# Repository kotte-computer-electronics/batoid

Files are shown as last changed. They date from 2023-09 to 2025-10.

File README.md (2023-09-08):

# batoid

_A 3D-printable, handwired, ergonomic keyboard_

Hero image

## Small footprint, big personality

Kotte Computer Electronics is proud to present the latest revolution in ergonomic personal computing peripherals - the Batoid Erlanomic keyboard.

The tilted, split layout of 43 staggered keys with an incline of 8 degrees is designed with your optimal performance in mind.

The two built in LED indicators conveniently show what side of the keyboard you are typing on, and blinks in a forwards-and-back manner during high typing speeds.

The bottom row features one extra key, this gives you the opportunity to add an easily accessible extra modifier.

The case is held together with M3 nuts and bolts, and the 3D-printed plate is mounted with a 3-5mm sealing strip, giving you a comfortable, soft typing experience with materials found at your local hardware store.

The Kotte Computer Electronics Batoid allows you to maximize your productivity and enjoyment, at work and home.

## Inspiration

I've wanted an Alice-like 40's board for quite a while, so when @theerland on the Swedish MK-Discord server said he wanted one too, inspiration struck.

The name Batoid comes from the fact that it looks a bit like a member of the batoidea ~family~ superorder of fish (thanks to [KBD news](https://kbd.news/Batoid-2112.html) for the correction). [Here's one I met a couple of years ago](./kotte-with-batoid.png). 

The keyboard looks pretty happy, and blinks it's eyes when you type - a feature that is completely useless, but cute as shit.

## Sound test

Don't believe in the quality of the mounting? [Here's a sound test](https://www.youtube.com/watch?v=9PGgU88DhRI).

## Some more glam shots, by Erland

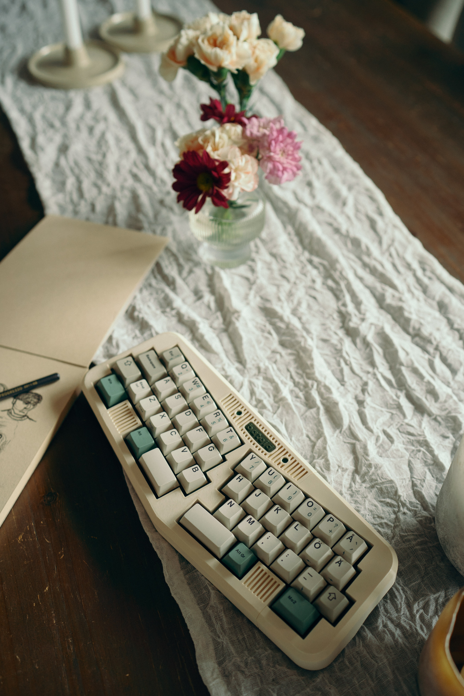
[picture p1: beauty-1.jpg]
Beauty Shot 1

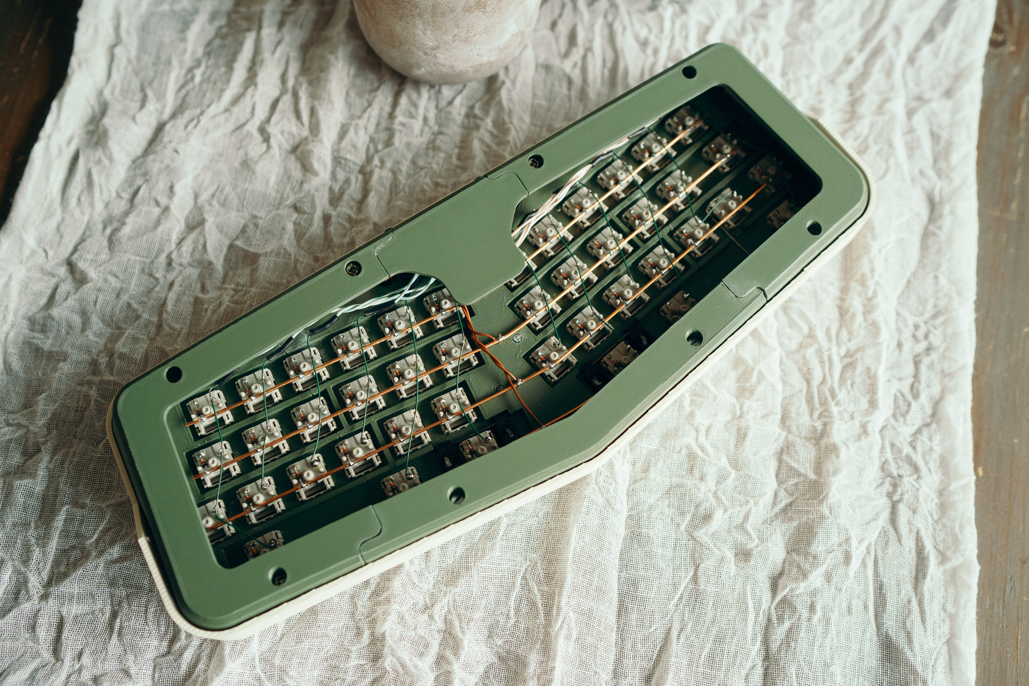
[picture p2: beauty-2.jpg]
Beauty Shot 2


## Some not as beautiful (but informative) CAD shots

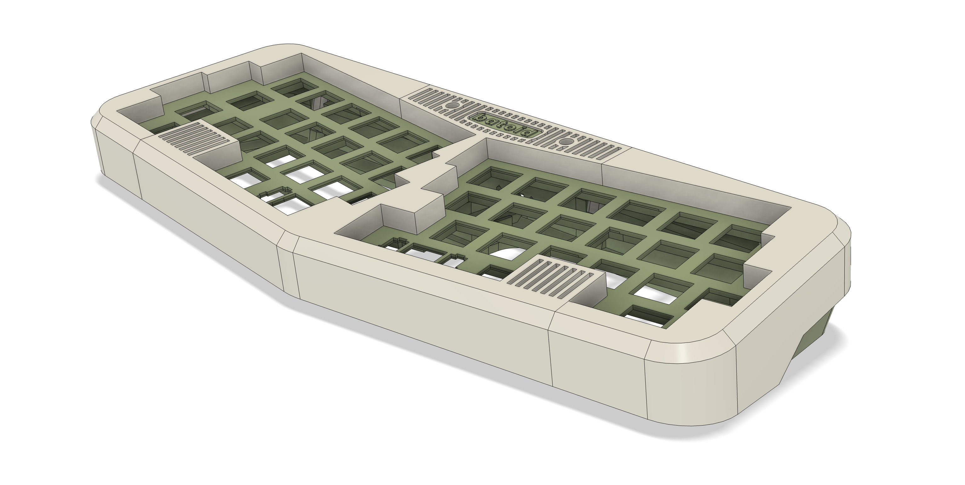
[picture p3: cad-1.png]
CAD 1

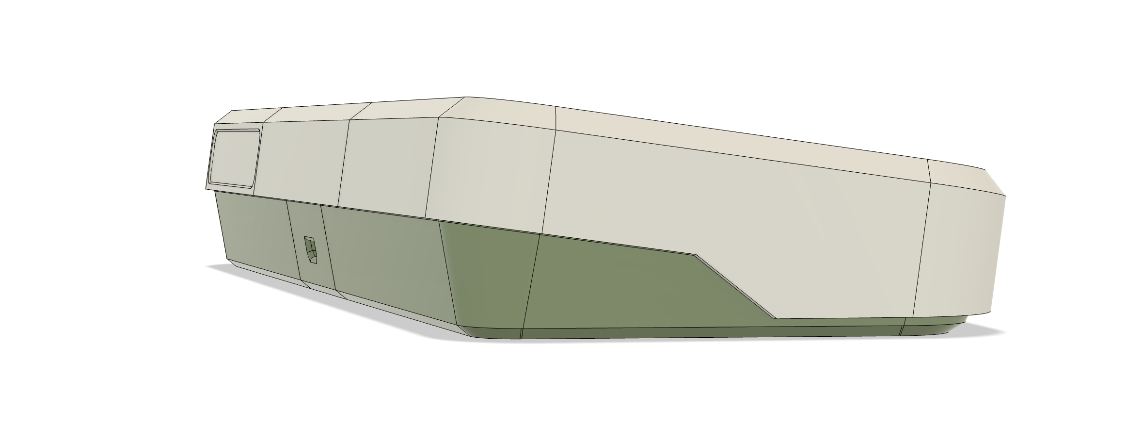
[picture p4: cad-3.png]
CAD 3

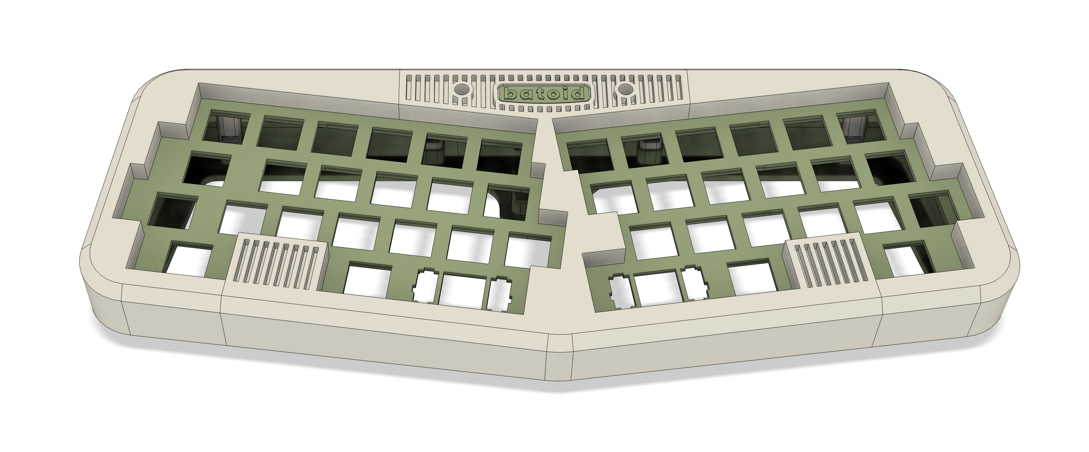
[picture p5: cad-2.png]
CAD 2


## Bill of materials

- 43 switches with MX footprint
- 43 diodes
- 2 2U plate mount stabilizers (optional)
- 1 Pro Micro
- A length of 3-5mm sealing strip with P profile
- 8 M3 nuts and bolts
- 2 5mm LED's (preferrably with built in resistors)
- 4 rubber feet
- CA glue
- Tiny ZIP tie for the MCU (usually not needed, but nice to have just in case)

## Building

The keyboard comes in a number of parts, split up to fit on a regular home-size 3D printer with minimal supports. Depending on your printer it can be a good idea to print it with brims.

- The top case parts are meant to be printed upside down, with painted on supports for the pegs.
- The bottom case parts are meant to be printed right side up.
- Take an extra look at the plate parts to find their correct orientations. No supports should be needed here.

Join the parts with CA glue, using the pegs as guides. This will produce a full top, bottom and plate.

### Wiring

Notice the folded key at the bottom of the grid.

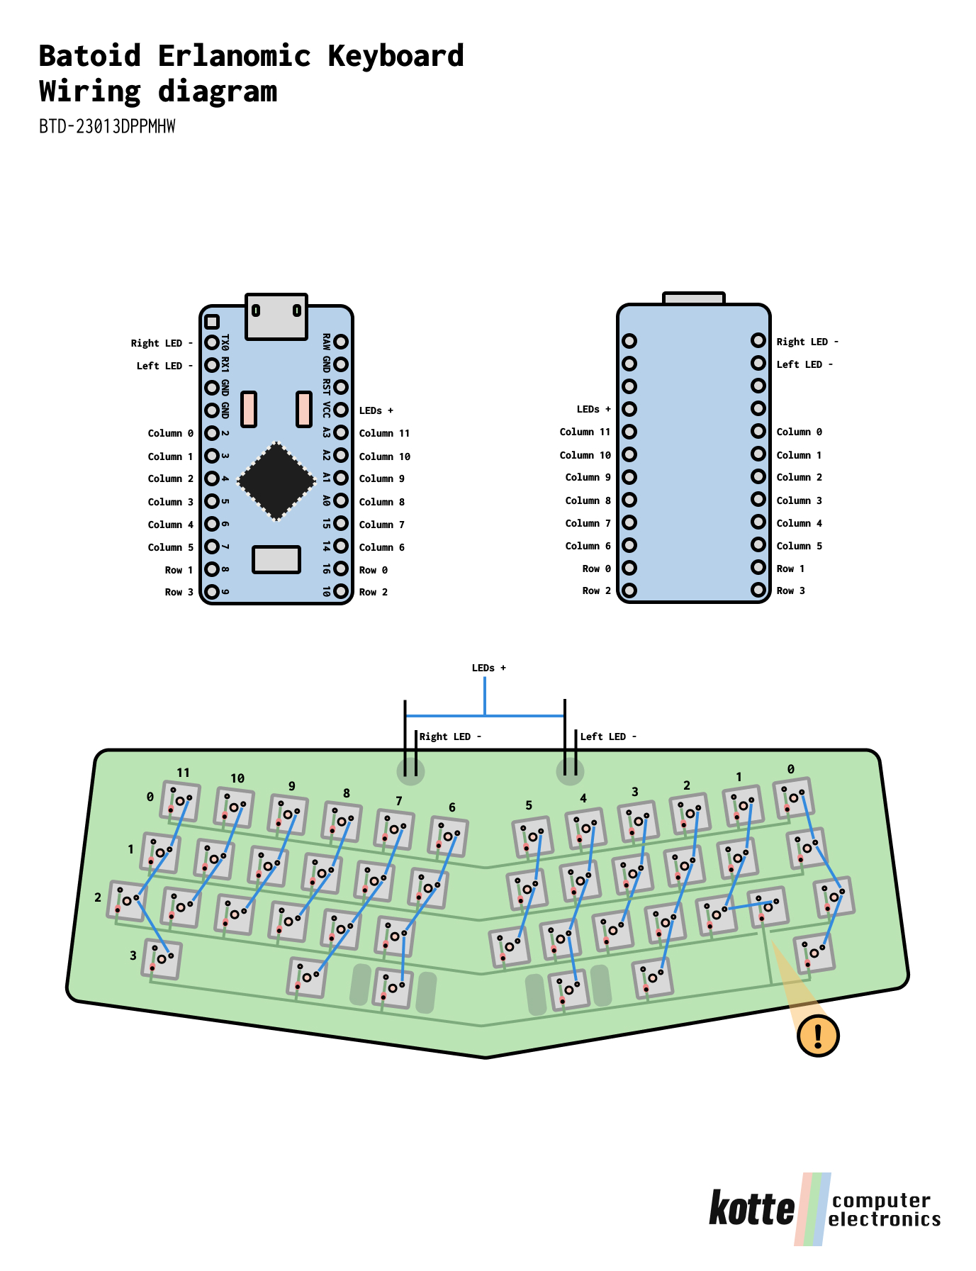
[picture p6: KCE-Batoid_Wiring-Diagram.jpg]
Wiring Diagram


### Sealing strip mounting

The plate rests on a ledge, on top of self-adhesive sealing strip. This might sound weird, but it's one of the nicer mounts I've tried, even if you disregard the cheap price.

Sealing Strip Example

### Building the case

The plate is sandwiched between the top and bottom. In the top, there are 8 legs with slots for M3 bolts. These can be friction fit, but a small dab of CA glue can provide extra security. Make sure to insert the bolts with a point forwards, matching the slots shape:

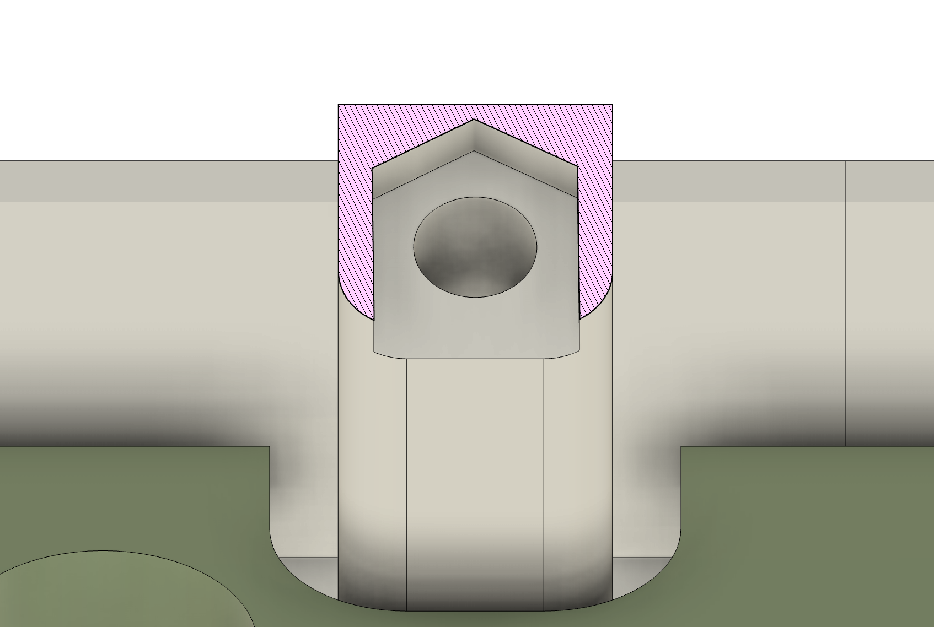
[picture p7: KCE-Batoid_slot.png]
Slot Shape


### Sticker

On the back is a space for a sticker, found in the `/print` folder. If you decide to print it, make sure to write the date you finished the build in the "controlled" field. Preferrably with a ballpoint pen, or thin sharpie, to match the vintage look.

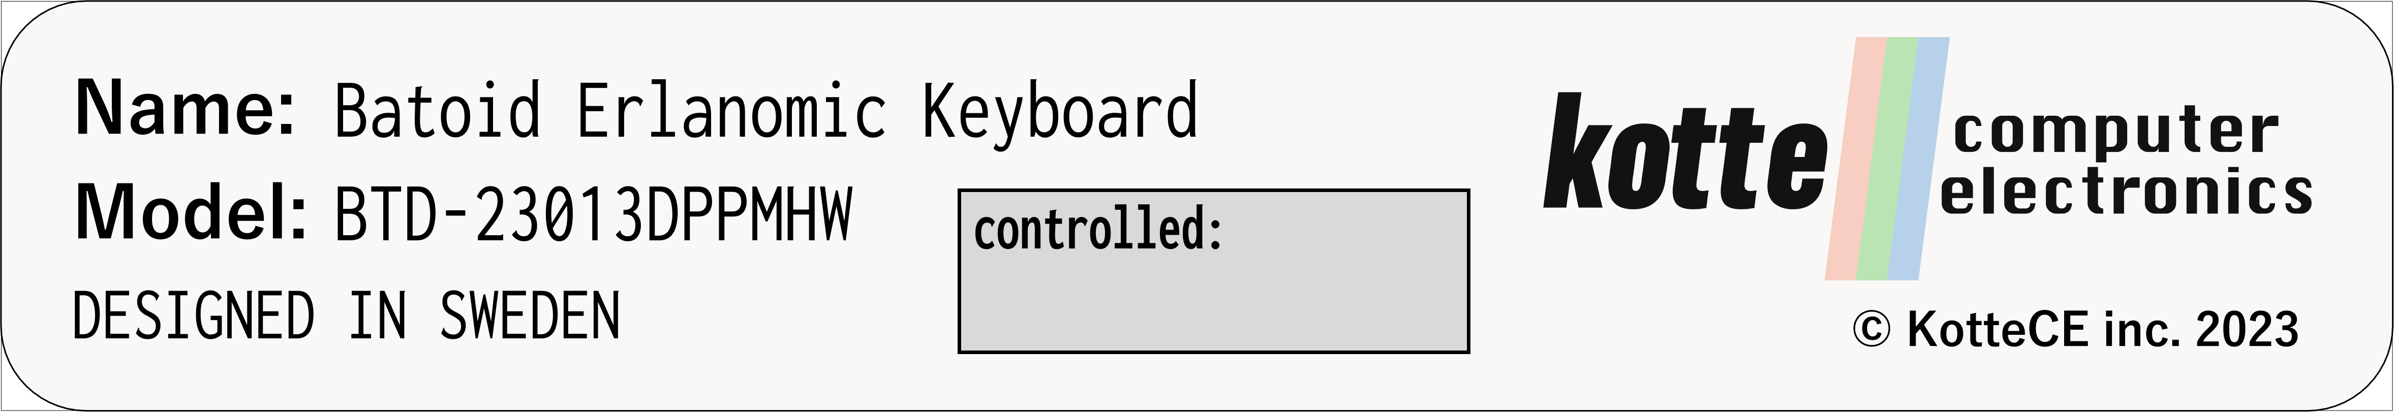
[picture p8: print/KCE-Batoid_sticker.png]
Sticker


## Firmware

### The hard way

Drop the `kotte` folder into the `qmk_firmware/keyboards` folder. Use the QMK CLI as you would normally do.

The keyboard has thre mappings:

- default: based on Corne, but taking the extra key into account. I don't really use a standard international mapping, so it might be weird.
- swekce: the default mapping that I use on most of my keyboards. it's higly personal, and features ÅÄÖ bc sweden.

### The easy way

My friend Erland hacked together a hex file that that allows for VIA. Just flash the built file (), and enjoy. It's messed up by default, but let's face it, you're not using VIA for the default mappings.

### WARNING (+ Erland mod)

The batoid does not feature a reset switch, so don't forget to have a reset key in your mapping. Or do as Erland did and jam two nails into the back and hook them up to the `reset` and `ground` pins to short them manually:

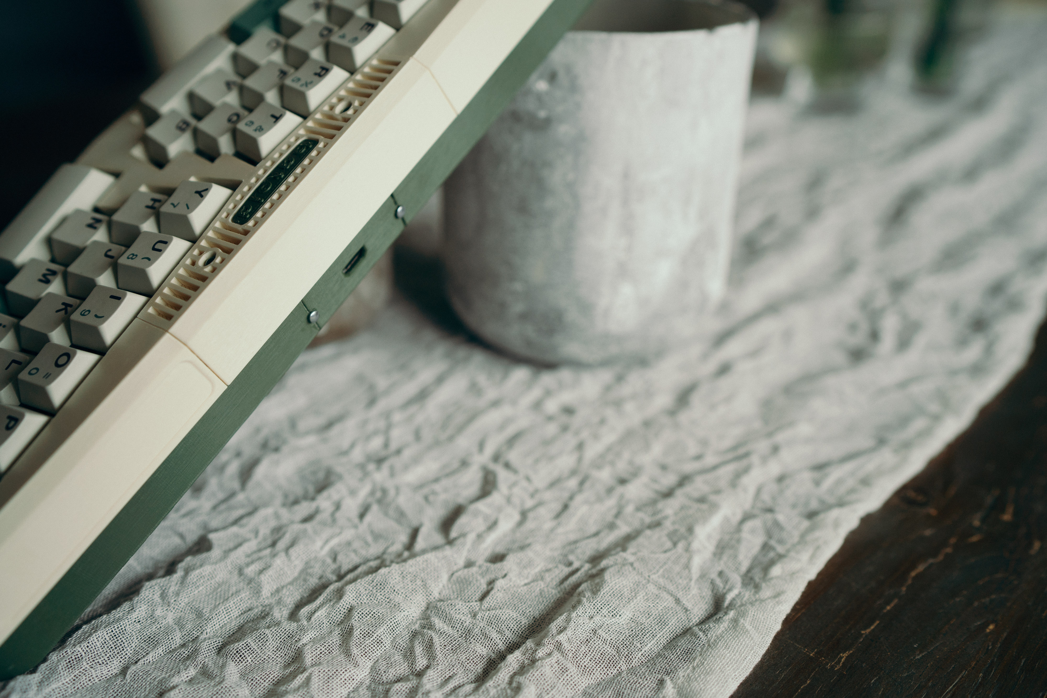
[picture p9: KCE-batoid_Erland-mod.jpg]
Erland Mod


## Contributions

I've been holding off on sharing this for a long time, mostly because the firmware and build instructions are far from perfect. If you want to help me out, it's very welcome, both in terms of feedback and pull requests!

## Donations

The batoid is available for free, but if you enjoy it, [any donation would be greatly appreciated](https://www.paypal.com/donate/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). This would help me buy more parts, components and filament to design more keyboards.

# License

</a></p>

<p xmlns:cc="http://creativecommons.org/ns#" xmlns:dct="http://purl.org/dc/terms/"><a property="dct:title" rel="cc:attributionURL" href="https://github.com/kotte-computer-electronics/batoid">Batoid</a> by <a rel="cc:attributionURL dct:creator" property="cc:attributionName" href="https://github.com/kotte-computer-electronics">Kotte Computer Electronics</a> is licensed under <a href="http://creativecommons.org/licenses/by-nc-sa/4.0/?ref=chooser-v1" target="_blank" rel="license noopener noreferrer" style="display:inline-block;">CC BY-NC-SA 4.0</a>

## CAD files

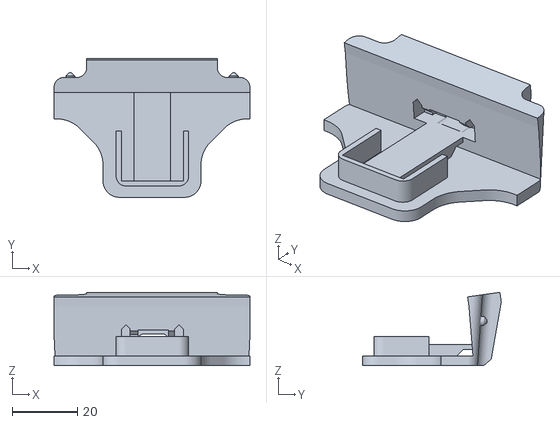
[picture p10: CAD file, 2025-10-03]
stl/BATOID Bottom Center Back USB C.stl
60.0 x 42.4 x 22.5

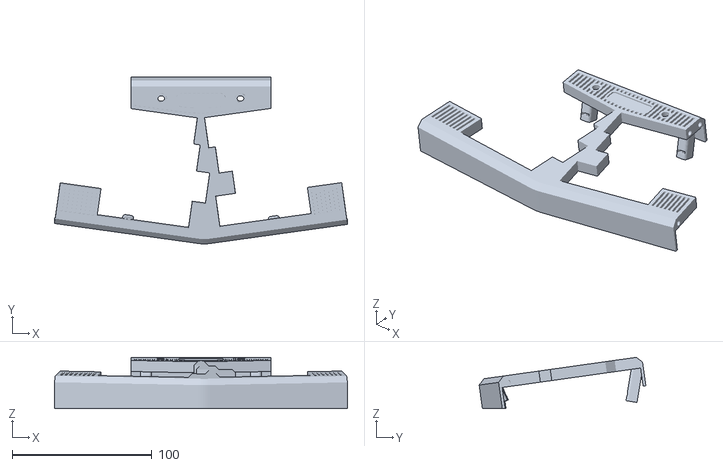
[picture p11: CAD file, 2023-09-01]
stl/BATOID Top Center.stl
209.3 x 119.1 x 36.6

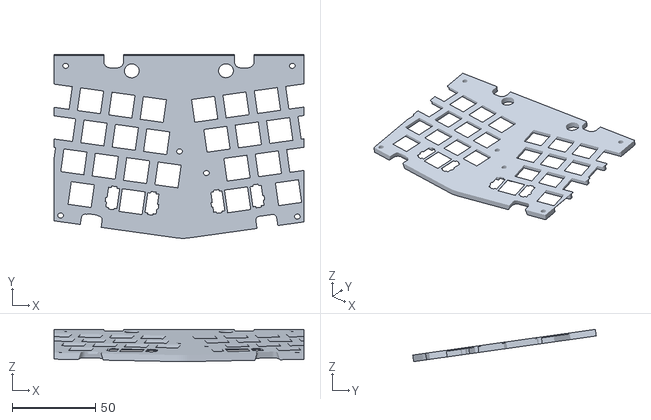
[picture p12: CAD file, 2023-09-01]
stl/BATOID Plate Center.stl
150.3 x 110.4 x 19.4

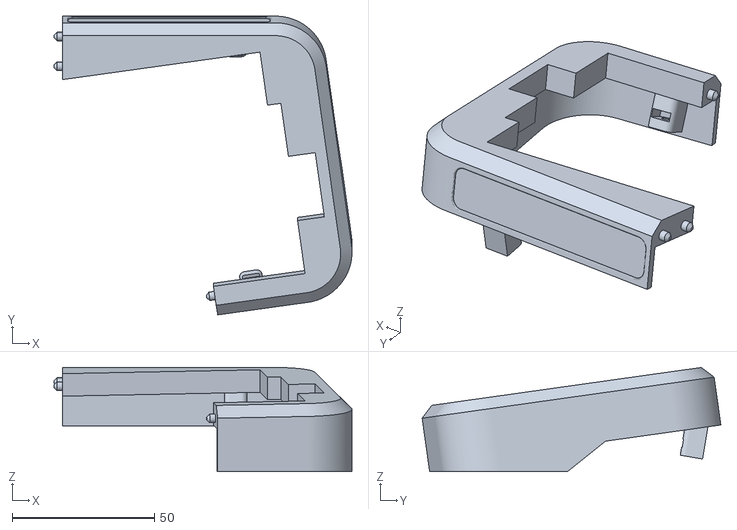
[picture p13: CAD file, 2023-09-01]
stl/BATOID Top Right.stl
104.9 x 105.2 x 36.6

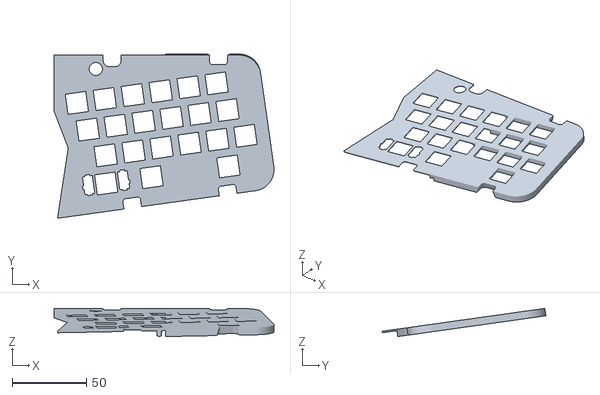
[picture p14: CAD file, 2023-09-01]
stl/BATOID Plate Right.stl
148.5 x 110.5 x 19.0

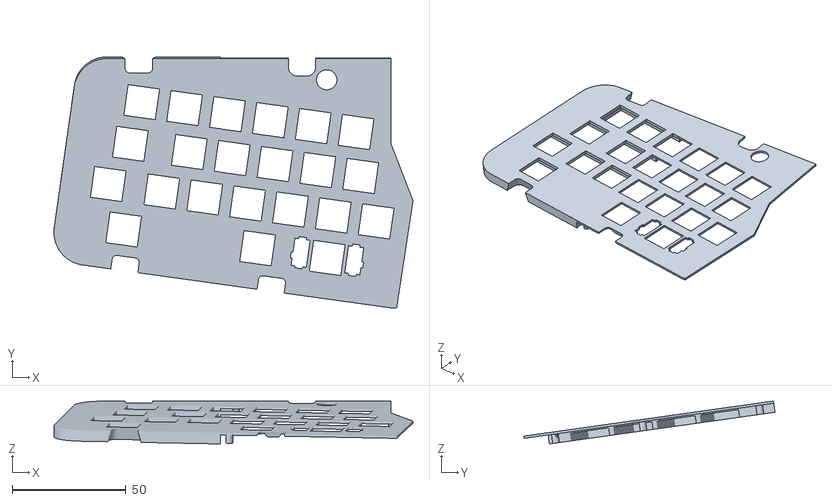
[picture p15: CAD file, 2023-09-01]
stl/BATOID Plate Left.stl
158.0 x 110.5 x 18.9

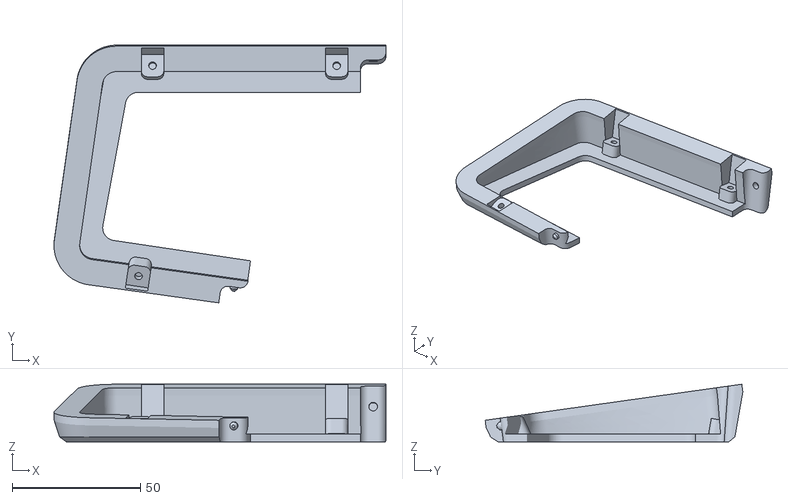
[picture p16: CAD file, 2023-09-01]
stl/BATOID Bottom Left.stl
129.5 x 100.5 x 22.5

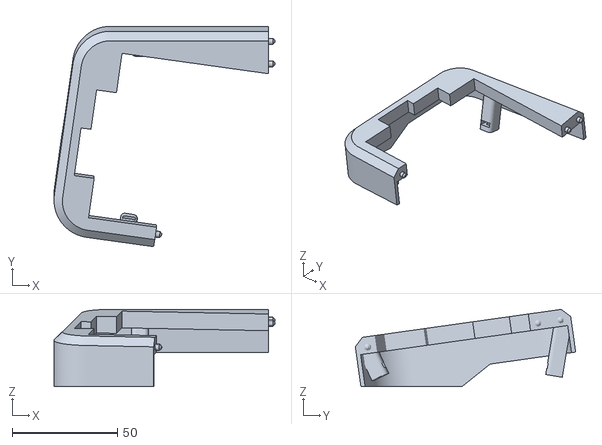
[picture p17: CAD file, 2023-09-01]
stl/BATOID Top Left.stl
104.8 x 104.6 x 36.6

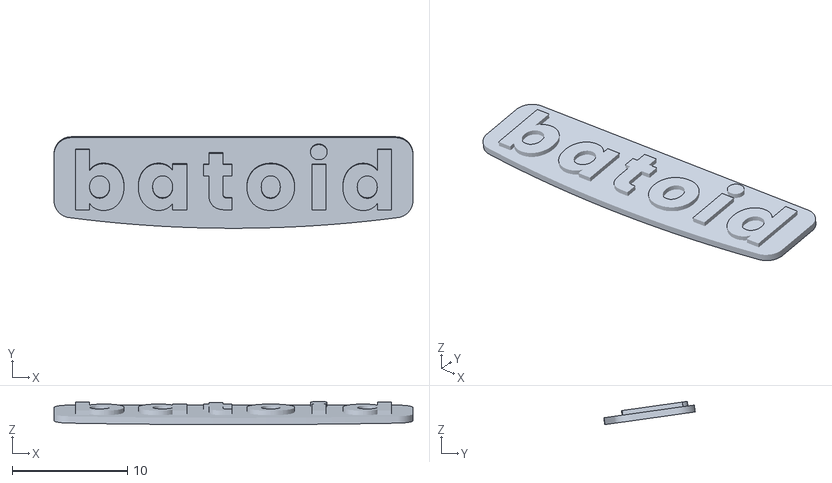
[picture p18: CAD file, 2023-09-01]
stl/BATOID Badge.stl
31.1 x 7.93 x 2.02

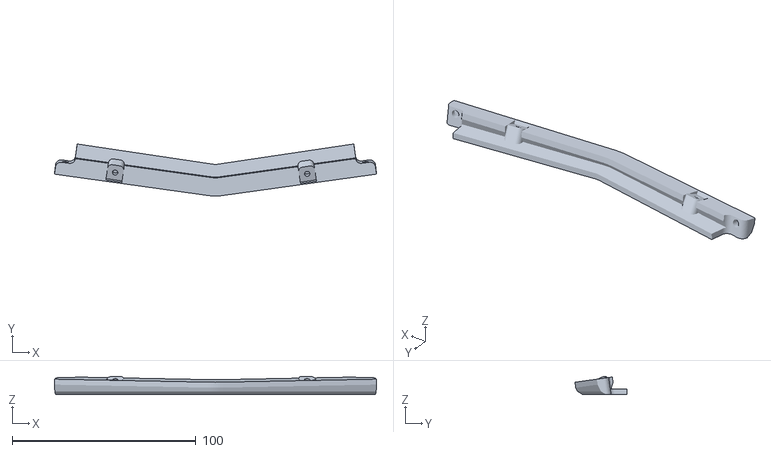
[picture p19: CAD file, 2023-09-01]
stl/BATOID Bottom Center Front.stl
175.2 x 28.3 x 9.89

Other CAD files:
stl/BATOID Bottom Center Back.stl
stl/BATOID Bottom Right.stl

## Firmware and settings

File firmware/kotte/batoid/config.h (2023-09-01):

#ifndef CONFIG_H
#define CONFIG_H

#include "config_common.h"

/* USB Device descriptor parameter */
#define VENDOR_ID 0xFEED
#define PRODUCT_ID 0x6060
#define DEVICE_VER 0x0001
#define MANUFACTURER KotteComputerElectronics
#define PRODUCT batoid
#define DESCRIPTION Keyboard

/* key matrix size */
#define MATRIX_ROWS 4
#define MATRIX_COLS 12

/* key matrix pins */
#define MATRIX_ROW_PINS \
    { B2, B4, B6, B5 }
#define MATRIX_COL_PINS \
    { D1, D0, D4, C6, D7, E6, B3, B1, F7, F6, F5, F4 }
#define UNUSED_PINS

#define LED_PIN_L D3
#define LED_PIN_R D2

/* COL2ROW or ROW2COL */
#define DIODE_DIRECTION COL2ROW

/* Set 0 if debouncing isn't needed */
#define DEBOUNCING_DELAY 5

/* Mechanical locking support. Use KC_LCAP, KC_LNUM or KC_LSCR instead in keymap */
#define LOCKING_SUPPORT_ENABLE

/* Locking resynchronize hack */
#define LOCKING_RESYNC_ENABLE

/* key combination for command */
#define IS_COMMAND() (keyboard_report->mods == (MOD_BIT(KC_LSHIFT) | MOD_BIT(KC_RSHIFT)))

/* prevent stuck modifiers */
#define PREVENT_STUCK_MODIFIERS

#endif

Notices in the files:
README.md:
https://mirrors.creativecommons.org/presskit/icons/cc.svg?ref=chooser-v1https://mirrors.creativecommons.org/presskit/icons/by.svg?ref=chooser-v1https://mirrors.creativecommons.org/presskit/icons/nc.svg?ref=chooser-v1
